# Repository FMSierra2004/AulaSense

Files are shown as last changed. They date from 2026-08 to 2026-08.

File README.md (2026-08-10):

# AulaSense

Repositorio principal para controlar el hardware, firmware y documentación de AulaSense.

## Estado actual

- Hardware: HW 0.1 DRAFT
- Firmware: FW 0.1.0-dev
- Etapa: planificación y prototipo inicial

## Organización

- `hardware/kicad`: esquema y PCB.
- `hardware/libraries`: símbolos y huellas propias.
- `hardware/manufacturing`: entregables para fabricación.
- `firmware`: código fuente del dispositivo.
- `docs`: arquitectura, planificación y compatibilidad.

## Versionado

El hardware utiliza versión y revisión física, por ejemplo `HW 1.0 Rev A`.

El firmware utiliza versiones `MAYOR.MENOR.CORRECCIÓN`, por ejemplo `FW 1.2.3`.

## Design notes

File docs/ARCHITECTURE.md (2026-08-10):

# Arquitectura de AulaSense

## Hardware

- Microcontrolador: pendiente.
- Sensores: pendiente.
- Alimentación: pendiente.
- Comunicaciones: pendiente.
- Interfaces y conectores: pendiente.

## Firmware

- Lenguaje y framework: pendiente.
- Controladores de sensores: pendiente.
- Comunicaciones: pendiente.
- Actualización de firmware: pendiente.
- Registro y diagnóstico: pendiente.

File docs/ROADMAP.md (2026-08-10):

# Plan de desarrollo

- [x] Crear la estructura inicial del repositorio.
- [ ] Definir requisitos funcionales de AulaSense.
- [ ] Seleccionar microcontrolador, sensores y comunicaciones.
- [ ] Diseñar el diagrama de bloques.
- [ ] Completar y revisar el esquema electrónico.
- [ ] Diseñar y validar la PCB.
- [ ] Fabricar HW 1.0 Rev A.
- [ ] Desarrollar el firmware inicial.
- [ ] Realizar pruebas de integración.
- [ ] Publicar la primera versión estable.

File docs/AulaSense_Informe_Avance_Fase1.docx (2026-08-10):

AulaSense

Informe de avance — Diseño de hardware

Fase 1: Esquemático electrónico — COMPLETADA

Juan Sebastián Sierra Arenas · Ficha 2879896 · SENA CEET · 10 de agosto de 2026

# 1. Resumen ejecutivo

Se completó el diseño del esquemático electrónico de AulaSense en KiCad 10.0, validado sin errores ni advertencias. El trabajo cubre el entregable de la sección 3.8 del plan de negocios (planos y repositorio técnico) y deja el proyecto listo para iniciar el diseño de la PCB.

Se adoptó una decisión de arquitectura clave: una sola placa para los tres kits (Básico, Educativo y Premium), diferenciados por los componentes que se sueldan en cada versión. Esto reduce a un tercio el trabajo de diseño, validación y fabricación, y es coherente con lo planteado en el plan sobre que los tres productos comparten el 70% de sus actividades de ensamble.

## Estado de las fases

Fase | Estado | Observación
Repositorio Git | Completada | Monorepo publicado en GitHub
Fase 1 — Esquemático | Completada | ERC con cero infracciones
Fase 2 — PCB | Pendiente | Requiere verificar pinout físico
Fase 3 — Fabricación | Pendiente | Gerbers y archivos de taladro

# 2. Entregables completados

## 2.1 Repositorio de control de versiones

Se estableció un monorepositorio Git que integra hardware, firmware y documentación en un solo historial versionado, publicado en GitHub bajo el usuario FMSierra2004.

- Estructura de carpetas: docs/, hardware/ (kicad, libraries, manufacturing) y firmware/ (src, include, config, tests)
- Archivo .gitignore configurado para excluir residuos propios de KiCad: archivos .kicad_prl, carpetas de respaldo, caché de huellas y archivos de bloqueo
- Archivo .gitattributes que declara los formatos KiCad como texto, de modo que los cambios sean legibles en cada commit
- Esquema de versionado definido: HW 0.1 DRAFT para el diseño actual, HW 1.0 Rev A para el primer hardware fabricado

## 2.2 Biblioteca de símbolos propia

Se creó la biblioteca AulaSense.kicad_sym en hardware/libraries/, con dos símbolos que representan el módulo ESP32 DevKit V1 de 30 pines.

La decisión de representar el módulo como dos conectores de 15 pines (Header_Left y Header_Right) en lugar de dibujar el chip ESP32 responde a la realidad física del diseño: la PCB es una placa portadora donde el módulo comercial se enchufa en zócalos hembra. Lo que la placa contiene eléctricamente son dos conectores, no un microcontrolador.

Cada pin recibió nombre y tipo eléctrico correcto. Los pines GPIO34, 35, 36 y 39 se marcaron como Entrada porque son de solo lectura por hardware; el pin 3V3 se marcó como Salida de alimentación porque el regulador AMS1117 está dentro del módulo. Estas definiciones permiten que el verificador de reglas eléctricas detecte usos incorrectos de forma automática.

## 2.3 Asignación de pines GPIO

Se definió la asignación definitiva de señales, corrigiendo dos problemas del planteamiento inicial.

Señal | GPIO | Pin físico | Justificación
SDA | 21 | Derecho-5 | Bus I²C por defecto
SCL | 22 | Derecho-2 | Bus I²C por defecto
DHT_DATA | 4 | Derecho-11 | Bidireccional para protocolo 1-Wire
MQ_AOUT | 34 | Izquierdo-12 | ADC1, sin conflicto con Wi-Fi
PIR_OUT | 13 | Izquierdo-3 | Entrada digital
REED | 27 | Izquierdo-6 | Entrada con pull-up interno
LED_R | 25 | Izquierdo-8 | Salida digital
LED_V | 26 | Izquierdo-7 | Salida digital
BUZZ | 14 | Izquierdo-5 | Salida con modulación PWM
BTN1 | 32 | Izquierdo-10 | Pull-up interno disponible
BTN2 | 33 | Izquierdo-9 | Pull-up interno disponible
BTN3 | 18 | Derecho-7 | Pull-up interno disponible

Corrección 1: el botón BTN3 se trasladó de GPIO35 a GPIO18. El GPIO35 es de solo entrada y carece de resistencia de pull-up interna, por lo que habría requerido un componente externo. Además es uno de los pocos canales ADC1 disponibles y conviene reservarlo para una futura entrada analógica.

Corrección 2: la señal REED se trasladó de GPIO14 a GPIO27, y el buzzer ocupó el GPIO14. Durante el arranque del ESP32, el GPIO14 emite pulsos PWM; en un buzzer eso produce un chasquido inofensivo, pero en una entrada que debe leer un estado estable habría causado lecturas erróneas.

Se dejaron deliberadamente libres los pines GPIO23, 19, 5, 17, 16 y 35, previendo la ampliación a la versión 2.0 contemplada en el plan. Se excluyeron GPIO2, 12 y 15 por ser pines de configuración de arranque, y GPIO1 y GPIO3 por corresponder al puerto de programación.

## 2.4 Bloques funcionales del esquemático

El esquema se organizó en siete bloques independientes conectados mediante etiquetas de señal, evitando el cruce de cables y facilitando la lectura del plano.

Bloque | Componentes principales
Módulo ESP32 | J1, J2 — zócalos hembra de 15 pines
Alimentación | J3, F1, D1, C1, C2, D2, R1
Botones | SW1–SW3, C3–C5
Notificación | D3, D4, R2, R3, Q1, R4, J4
Sensores ambientales | J5 (DHT22), J6 (PIR), J7 (reed), R5
Visualización | J8 — pantalla OLED I²C
Calidad del aire | J9 (MQ-135), R6, R7, C6

Bloque de alimentación. Se implementó una cadena de protección completa: la entrada de 5 V pasa por un polyfuse de 1,1 A que limita la corriente ante un cortocircuito, luego por un diodo Schottky SS34 que protege contra inversión de polaridad. Un condensador electrolítico de 470 µF absorbe el pico de corriente que genera el calentador del MQ-135 al encender, y uno cerámico de 100 nF filtra el ruido de alta frecuencia. Un LED verde con resistencia de 1 kΩ indica que la placa tiene alimentación.

Bloque de botones. Cada pulsador cierra a tierra y se apoya en el pull-up interno del ESP32, ahorrando tres resistencias por unidad. Un condensador de 100 nF en paralelo con cada pulsador filtra el rebote mecánico: junto al pull-up interno de aproximadamente 45 kΩ produce una constante de tiempo cercana a 4,5 ms, suficiente para eliminar los rebotes típicos sin que el botón se perciba lento. Esto es relevante porque el Kit Educativo permite al docente configurar umbrales mediante botones físicos.

Bloque de notificación. Los LEDs indicadores llevan resistencias de 220 Ω (rojo) y 330 Ω (verde) para igualar el brillo percibido. El buzzer se conmuta mediante un transistor BC337 con resistencia de base de 1 kΩ, porque un pin del ESP32 no puede entregar directamente la corriente que demanda el zumbador.

Bloque de calidad del aire. La salida analógica del MQ-135 opera a 5 V y debe reducirse antes de entrar al ADC del ESP32, que trabaja a 3,3 V. Se dimensionó un divisor con resistencias de 10 kΩ y 15 kΩ que entrega 3,0 V a fondo de escala, dejando margen de seguridad respecto al límite del convertidor. Un condensador de 100 nF filtra el ruido que introduce el calentador del sensor.

## 2.5 Validación eléctrica

El verificador de reglas eléctricas (ERC) de KiCad reporta cero errores y cero advertencias sobre el esquema completo. Durante el proceso se resolvieron progresivamente 17 infracciones iniciales.

- Se añadieron banderas PWR_FLAG en las redes de 5 V y tierra, declarando que la alimentación proviene de una fuente externa
- Se marcaron con bandera de no conectado los trece pines del módulo que quedan sin uso, evitando advertencias que enmascararían errores reales
- Se verificó que cada etiqueta de señal aparezca en al menos dos puntos, confirmando que ninguna red quedó aislada

## 2.6 Huellas y archivos de fabricación

Se asignaron las 31 huellas correspondientes a componentes de agujero pasante. Se exportó la lista de materiales en formato CSV con agrupamiento por valor, y el plano del esquema en PDF con el bloque de título institucional completo.

# 3. Decisiones de diseño

Las siguientes decisiones deben quedar registradas en el archivo hardware/CHANGELOG.md del repositorio.

Decisión | Justificación
Tecnología de agujero pasante en lugar de montaje superficial | El plan asigna 25 minutos de soldadura manual por unidad y la inversión en equipo no contempla horno de reflujo. Además facilita la reparación durante los 12 meses de garantía.
Bornera de dos pines en lugar de receptor USB-C | El conector USB-C requiere dos resistencias de 5,1 kΩ en los pines CC para que un cargador moderno entregue corriente, y su encapsulado dificulta la soldadura manual. Se pospone para HW 1.0.
Sin pulsador de reinicio en la placa | El módulo DevKit ya incorpora uno, y la ficha técnica del producto prohíbe al usuario abrir la carcasa.
Una sola PCB para los tres kits | Las versiones se diferencian por los componentes que se sueldan. Evita triplicar el diseño, la validación y los archivos de fabricación.
Divisor resistivo de 10 kΩ y 15 kΩ | La combinación inicial de 10 kΩ y 20 kΩ entregaba 3,33 V, superando la tensión de alimentación del pin. La nueva relación entrega 3,0 V con margen.
Antirrebote por hardware en los botones | Tres condensadores de bajo costo evitan lecturas múltiples cuando el docente configura umbrales, problema que generaría reclamos de garantía.

# 4. Puntos pendientes

## 4.1 Verificación del pinout físico (crítico)

Todo el diseño asume la distribución estándar del módulo DOIT ESP32 DevKit V1 de 30 pines. Existen variantes de fabricantes distintos con el orden alterado. Debe compararse el esquema contra la serigrafía de la placa física antes de iniciar el trazado de la PCB.

Corregir un nombre de pin en el esquema toma menos de un minuto; detectar el error después de fabricar la placa implica perder la tirada completa.

## 4.2 Definiciones técnicas por confirmar

- Tipo de buzzer: el plan indica pasivo de 5 V; conviene confirmar si es magnético o piezoeléctrico, ya que el magnético requiere diodo de protección
- Orden de pines del módulo OLED: se asumió la secuencia GND, VCC, SCL, SDA, que es la más común pero no la única
- Corriente de la fuente: el plan especifica 5 V y 2 A en las tres fichas técnicas; debe mantenerse esa cifra para no contradecir el documento comercial
- Portapilas CR2032 para respaldo del reloj en el Kit Premium, requerido por la función de registro histórico de siete días

# 5. Trabajo previsto para la próxima sesión

1. Verificar el pinout contra el módulo ESP32 físico y corregir el esquema si hay diferencias
2. Importar el esquema al editor de placas mediante la función de actualización desde esquema
3. Definir el contorno de la PCB según la carcasa de 90 × 60 × 30 mm especificada para el Kit Básico
4. Ubicar los componentes considerando la posición de la ventana de la pantalla, los orificios de los LEDs y la rejilla de ventilación del sensor de gas
5. Trazar las pistas, dimensionando con mayor ancho las de alimentación por la corriente del calentador del MQ-135
6. Generar el plano de tierra en la capa inferior
7. Ejecutar el verificador de reglas de diseño hasta dejarlo sin infracciones
8. Etiquetar la versión como hw-0.1-pcb en el repositorio

# 6. Comandos para retomar el trabajo

Desde una terminal de PowerShell:

cd C:\Users\juan.sierra\Documents\AulaSense

git status

Luego abrir KiCad y cargar el proyecto desde hardware\kicad\AulaSense.kicad_pro. El esquema está validado y no requiere correcciones para continuar.

Documento generado el 10 de agosto de 2026 como registro de avance del proyecto AulaSense.

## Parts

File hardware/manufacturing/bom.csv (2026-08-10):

Reference | Qty | Value | Footprint | Datasheet
C1,C3,C4,C5,C6 | 5 | 100nF | Capacitor_THT:C_Disc_D5.0mm_W2.5mm_P5.00mm
C2 | 1 | 470µF/16V | Capacitor_THT:CP_Radial_D8.0mm_P3.50mm
D1 | 1 | SS34 | Diode_THT:D_DO-41_SOD81_P10.16mm_Horizontal
D2,D4 | 2 | Verde | LED_THT:LED_D5.0mm
D3 | 1 | Rojo | LED_THT:LED_D5.0mm
F1 | 1 | 1.1A | Resistor_THT:R_Axial_DIN0207_L6.3mm_D2.5mm_P7.62mm_Horizontal
J1 | 1 | ESP32_DevKitV1_Header_Left | Connector_PinSocket_2.54mm:PinSocket_1x15_P2.54mm_Vertical
J2 | 1 | ESP32_DevKitV1_Header_Right | Connector_PinSocket_2.54mm:PinSocket_1x15_P2.54mm_Vertical
J3 | 1 | Entrada 5V | Connector_PinHeader_2.54mm:PinHeader_1x02_P2.54mm_Vertical
J4 | 1 | Buzzer 5V | Connector_PinHeader_2.54mm:PinHeader_1x02_P2.54mm_Vertical
J5 | 1 | DHT22 | Connector_PinHeader_2.54mm:PinHeader_1x03_P2.54mm_Vertical
J6 | 1 | PIR HC-SR501 | Connector_PinHeader_2.54mm:PinHeader_1x03_P2.54mm_Vertical
J7 | 1 | Reed switch | Connector_PinHeader_2.54mm:PinHeader_1x02_P2.54mm_Vertical
J8 | 1 | OLED 0.96 I2C | Connector_PinHeader_2.54mm:PinHeader_1x04_P2.54mm_Vertical
J9 | 1 | MQ-135 | Connector_PinHeader_2.54mm:PinHeader_1x04_P2.54mm_Vertical
Q1 | 1 | BC337 | Package_TO_SOT_THT:TO-92_Inline
R1,R4 | 2 | 1k | Resistor_THT:R_Axial_DIN0207_L6.3mm_D2.5mm_P10.16mm_Horizontal
R2 | 1 | 220 | Resistor_THT:R_Axial_DIN0207_L6.3mm_D2.5mm_P10.16mm_Horizontal
R3 | 1 | 330 | Resistor_THT:R_Axial_DIN0207_L6.3mm_D2.5mm_P10.16mm_Horizontal
R5,R6 | 2 | 10k | Resistor_THT:R_Axial_DIN0207_L6.3mm_D2.5mm_P10.16mm_Horizontal
R7 | 1 | 15k | Resistor_THT:R_Axial_DIN0207_L6.3mm_D2.5mm_P10.16mm_Horizontal
SW1,SW2,SW3 | 3 | SW_Push | Button_Switch_THT:SW_PUSH_6mm

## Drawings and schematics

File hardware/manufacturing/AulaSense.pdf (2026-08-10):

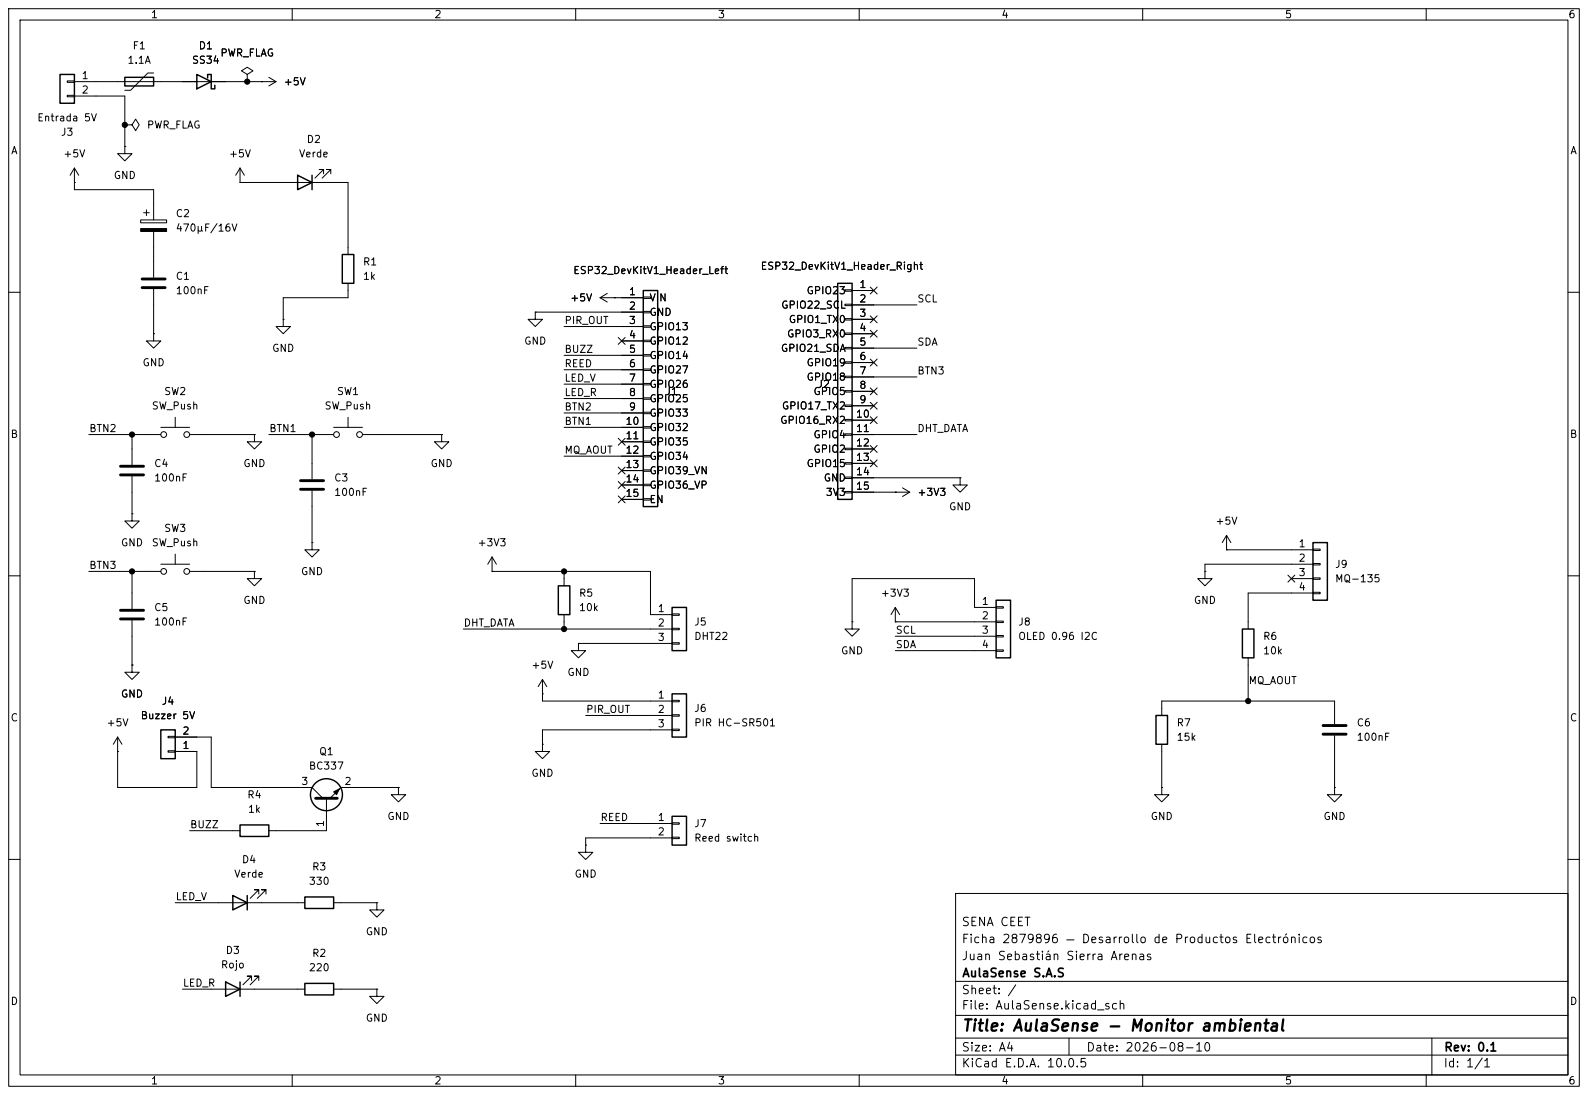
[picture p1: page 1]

Ficha 2879896 — Desarrollo de Productos Electrónicos
Juan Sebastián Sierra Arenas
AulaSense S.A.S
Sheet: /
File: AulaSense.kicad_sch
Title: AulaSense - Monitor ambiental

Size: A4 | Rev: 0.1
KiCad E.D.A. 10.0.5 | Id: 1/1

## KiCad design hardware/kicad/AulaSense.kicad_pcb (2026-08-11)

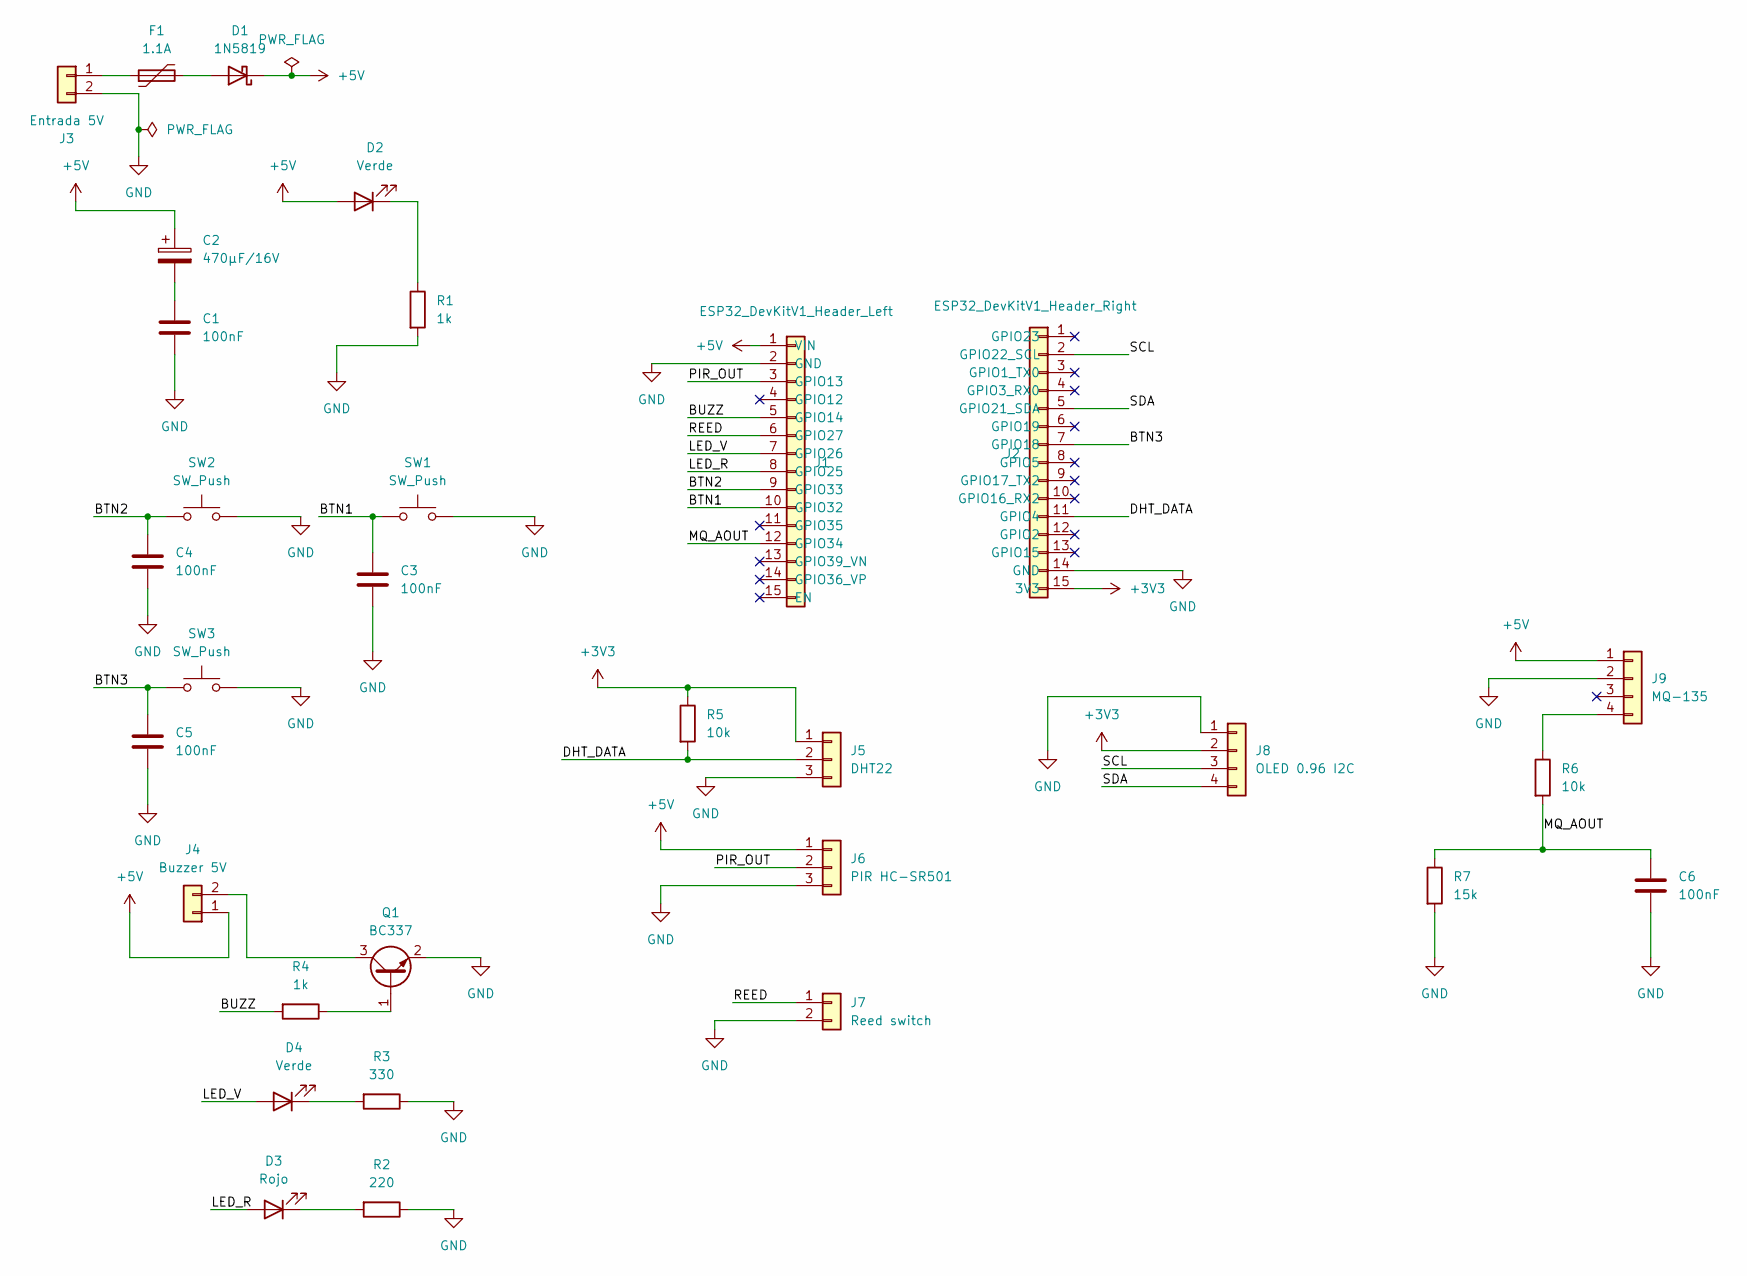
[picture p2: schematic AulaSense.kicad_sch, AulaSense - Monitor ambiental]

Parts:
C1, C3, C4, C5, C6: 100nF; C_Disc_D5.0mm_W2.5mm_P5.00mm
C2: 470µF/16V; CP_Radial_D8.0mm_P3.50mm
D1: 1N5819; D_DO-41_SOD81_P10.16mm_Horizontal
D2, D4: Verde; LED_D5.0mm
D3: Rojo; LED_D5.0mm
F1: 1.1A; Fuse_Bourns_MF-RG300
J1: ESP32_DevKitV1_Header_Left; PinSocket_1x15_P2.54mm_Vertical
J2: ESP32_DevKitV1_Header_Right; PinSocket_1x15_P2.54mm_Vertical
J3: Entrada 5V; PinHeader_1x02_P2.54mm_Vertical
J4: Buzzer 5V; PinHeader_1x02_P2.54mm_Vertical
J5: DHT22; PinHeader_1x03_P2.54mm_Vertical
J6: PIR HC-SR501; PinHeader_1x03_P2.54mm_Vertical
J7: Reed switch; PinHeader_1x02_P2.54mm_Vertical
J8: OLED 0.96 I2C; PinHeader_1x04_P2.54mm_Vertical
J9: MQ-135; PinHeader_1x04_P2.54mm_Vertical
Q1: BC337; TO-92_Inline
R1, R4: 1k; R_Axial_DIN0207_L6.3mm_D2.5mm_P10.16mm_Horizontal
R2: 220; R_Axial_DIN0207_L6.3mm_D2.5mm_P10.16mm_Horizontal
R3: 330; R_Axial_DIN0207_L6.3mm_D2.5mm_P10.16mm_Horizontal
R5, R6: 10k; R_Axial_DIN0207_L6.3mm_D2.5mm_P10.16mm_Horizontal
R7: 15k; R_Axial_DIN0207_L6.3mm_D2.5mm_P10.16mm_Horizontal
SW1, SW2, SW3: SW_Push; SW_PUSH_6mm

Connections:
+3V3: J2.15 (3V3), J5.1, J8.2, R5.1
+5V: C2.1, D1.1 (K), D2.2 (A), J1.1 (VIN), J4.1, J6.1, J9.1
/BTN1: C3.1, J1.10 (GPIO32), SW1.1
/BTN2: C4.1, J1.9 (GPIO33), SW2.1
/BTN3: C5.1, J2.7 (GPIO18), SW3.1
/BUZZ: J1.5 (GPIO14), R4.2
/DHT_DATA: J2.11 (GPIO4), J5.2, R5.2
/LED_R: D3.2 (A), J1.8 (GPIO25)
/LED_V: D4.2 (A), J1.7 (GPIO26)
/MQ_AOUT: C6.1, J1.12 (GPIO34), R6.2, R7.1
/PIR_OUT: J1.3 (GPIO13), J6.2
/REED: J1.6 (GPIO27), J7.1
/SCL: J2.2 (GPIO22_SCL), J8.3
/SDA: J2.5 (GPIO21_SDA), J8.4
GND: C1.2, C3.2, C4.2, C5.2, C6.2, J1.2 (GND), J2.14 (GND), J3.2, J5.3, J6.3, J7.2, J8.1, J9.2, Q1.2 (E), R1.2, R2.1, R3.1, R7.2, SW1.2, SW2.2, SW3.2
unnamed: C1.1, C2.2
unnamed: D1.2 (A), F1.2
unnamed: D2.1 (K), R1.1
unnamed: D3.1 (K), R2.2
unnamed: D4.1 (K), R3.2
unnamed: F1.1, J3.1
unnamed: J4.2, Q1.3 (C)
unnamed: J9.4, R6.1
unnamed: Q1.1 (B), R4.1

Board: 2 copper layers, 31 parts (0 on the bottom side), 24 nets, no tracks yet.

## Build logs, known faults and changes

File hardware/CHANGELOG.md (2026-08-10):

# Cambios de hardware

## HW 0.1 DRAFT - 2026-08-10

- Creación inicial del proyecto KiCad.
- Estructura de hardware preparada.

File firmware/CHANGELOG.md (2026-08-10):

# Cambios del firmware

## FW 0.1.0-dev - 2026-08-10

THT sobre SMD, bornera en vez de USB-C, sin botón de reset en placa, BTN3 movido de GPIO35 a GPIO18, REED de GPIO14 a GPIO27, divisor 10k/15k para el MQ-135.

- Creación de la estructura inicial.
- Firmware todavía sin plataforma seleccionada.

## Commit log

2026-08-10 chore: crea estructura inicial de AulaSense
    [AulaSense.kicad_pcb, AulaSense.kicad_sch]
2026-08-10 feat(hw): simbolos ESP32 DevKit V1 con pinout y tipos electricos
    [AulaSense.kicad_sch]
2026-08-10 feat(hw): asignacion de GPIO y etiquetas de senal en headers ESP32
    [AulaSense.kicad_pcb, AulaSense.kicad_sch]
2026-08-10 feat(hw): bloque de alimentacion con proteccion y PWR_FLAG
    [AulaSense.kicad_sch]
2026-08-10 feat(hw): bloque de botones con antirrebote RC
    [AulaSense.kicad_sch]
2026-08-10 feat(hw): bloque de notificacion con LEDs y buzzer
    [AulaSense.kicad_sch]
2026-08-10 feat(hw): conectores de sensores DHT22, PIR y reed
    [AulaSense.kicad_sch]
2026-08-10 feat(hw): bloque MQ-135 con divisor resistivo y filtro
    [AulaSense.kicad_sch]
2026-08-10 feat(hw): esquematico completo con ERC limpio
    [AulaSense.kicad_sch]
2026-08-10 feat(hw): esquematico completo, huellas THT, BOM y plano
    [AulaSense.kicad_sch, bom.csv]
2026-08-10 docs: informe de avance de la fase 1
    Esquematico validado con ERC limpio
2026-08-11 docs: informe de avance de la fase 1
2026-08-11 chore: excluir respaldos .bak del control de versiones
2026-08-11 chore: ignorar carpeta .history de VS Code
2026-08-11 fix(hw): D1 a 1N5819 THT y huella radial provisional para F1
    - D1: el SS34 solo existe en encapsulado SMA, se reemplaza por 1N5819 en DO-41
    - F1: MF-RG300 como huella provisional, paso 5,08 mm compatible con RXEF110
    [AulaSense.kicad_sch]
2026-08-11 feat(hw): contorno de PCB 80x50mm y reglas de diseno
    - Clase Power (0,6 mm) para +5V, +3V3 y GND
    - Restricciones: margen 0,2 mm, taladro min 0,3 mm, anular 0,15 mm
    [AulaSense.kicad_pcb]
